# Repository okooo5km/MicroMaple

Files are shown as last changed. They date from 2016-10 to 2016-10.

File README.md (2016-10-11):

# Micro Maple

**Micro Maple** is an opensource hardware like **Maple mini** created by Leaflab and disigned to realize our idea and creat our works more quickly and simply ! 

Basically, **STM32F103C8T6** works as the core -- it's very cheap and enough for our most ideas!

The features of **STM32F103C8T6**:

- ARM 32bits Cortex-M3 CPU
  - 72MHz, 1.25DMips/MHz(Dhrystone 2.1)
  - single cycle for Multiplication and Division
- 64K FLASH And 20K SRAM
- Two 12bits ADC, 1 us for transition
- 7 channel DMA for USART\Timer\ADC\SPI\IIC
- 16 External Interrupt
- 7 Timer
- Interface
  - 2 IIC
  - 3 USART
  - 3 SPI
  - CAN
  - USB2.0

# Micro Maple (中文)

**Micro Maple** 是类似于 **Maple Mini(由Leaflab设计)** 的开源硬件，设计初衷是让我们实现自己的想法和作品更加简单和快捷。

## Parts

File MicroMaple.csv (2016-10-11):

Reference | Value | Footprint | Datasheet
U1 | STM32F103C8T6 | Housings_QFP:LQFP-48_7x7mm_Pitch0.5mm
P1 | USB_OTG | myFootprints:USB_Micro-B-MK5
R3 | 22 | Resistors_SMD:R_0603
R4 | 22 | Resistors_SMD:R_0603
C5 | 47pF | Capacitors_SMD:C_0603
C6 | 47pF | Capacitors_SMD:C_0603
U2 | XC6206P332MR | TO_SOT_Packages_SMD:SOT-23
U3 | XC6206P332MR | TO_SOT_Packages_SMD:SOT-23
C8 | 10uF | Capacitors_SMD:C_0603
C9 | 10uF | Capacitors_SMD:C_0603
C7 | 100uF | SMD_Packages:SMD-1210_Pol
R8 | 0 | Resistors_SMD:R_0603
P2 | CONN_01X14 | myFootprints:Connector_FAD_14x1
P3 | CONN_01X14 | myFootprints:Connector_FAD_14x1
C2 | 1uF | Capacitors_SMD:C_0603
C3 | 1uF | Capacitors_SMD:C_0603
C4 | 1uF | Capacitors_SMD:C_0603
C1 | 1uF | Capacitors_SMD:C_0603
X1 | 8MHz_OSC | myFootprints:Resonator_3.2x1.5mm
C10 | 18pF | Capacitors_SMD:C_0603
C11 | 18pF | Capacitors_SMD:C_0603
R12 | 1K | Resistors_SMD:R_0603
D3 | GREEN | LEDs:LED_0603
R9 | 1K | Resistors_SMD:R_0603
D2 | PWR | LEDs:LED_0603
SW1 | USR_BUT | Buttons_Switches_SMD:SW_SPST_EVQP7C
R11 | 10K | Resistors_SMD:R_0603
R10 | 1K | Resistors_SMD:R_0603
R14 | 1K | Resistors_SMD:R_0603
R13 | 10K | Resistors_SMD:R_0603
SW2 | RST_BUTTON | Buttons_Switches_SMD:SW_SPST_EVQP7C
P4 | CONN_01X12 | myFootprints:Connector_FAD_12x1
R7 | 1.5K | Resistors_SMD:R_0603
R6 | 36K | Resistors_SMD:R_0603
R1 | 1K | Resistors_SMD:R_0603
R5 | 10K | Resistors_SMD:R_0603
R2 | 47K | Resistors_SMD:R_0603
Q1 | 8050 | TO_SOT_Packages_SMD:SOT-23
Q2 | 8050 | TO_SOT_Packages_SMD:SOT-23
D1 | D_Small | Diodes_SMD:SOD-123
P5 | CONN_01X01 | myFootprints:Debug_Pin_1
P6 | CONN_01X01 | myFootprints:Debug_Pin_1
P7 | CONN_01X01 | myFootprints:Debug_Pin_1
P8 | CONN_01X01 | myFootprints:Debug_Pin_1

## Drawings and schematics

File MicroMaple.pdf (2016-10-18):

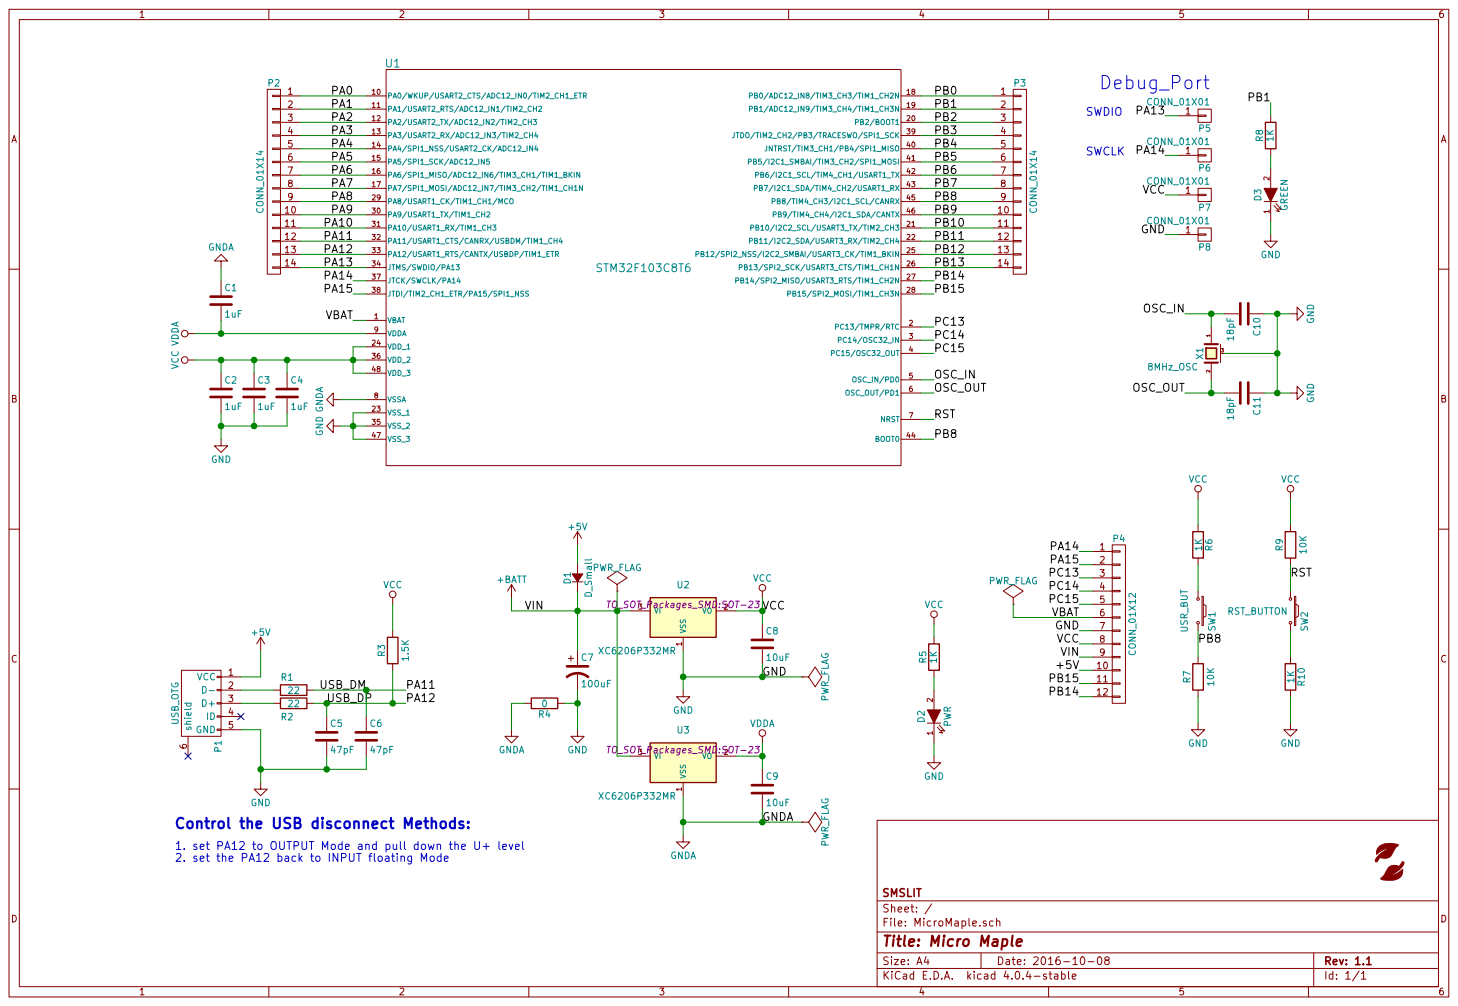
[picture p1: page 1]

14 P2 CONN_01X14 5 | 5

10 | 10
11 | 11
12 | 12
13 | 13

1 2 D2 PWR GND VCC USR_BUT SW1 R7 10K 1KR6 VCC

Control the USB disconnect Methods:

1. set PA12 to OUTPUT Mode and pull down the U+ level
2. set the PA12 back to INPUT floating Mode

File: MicroMaple.sch Sheet: / SMSLIT

Id: 1/1 Title: Micro Maple

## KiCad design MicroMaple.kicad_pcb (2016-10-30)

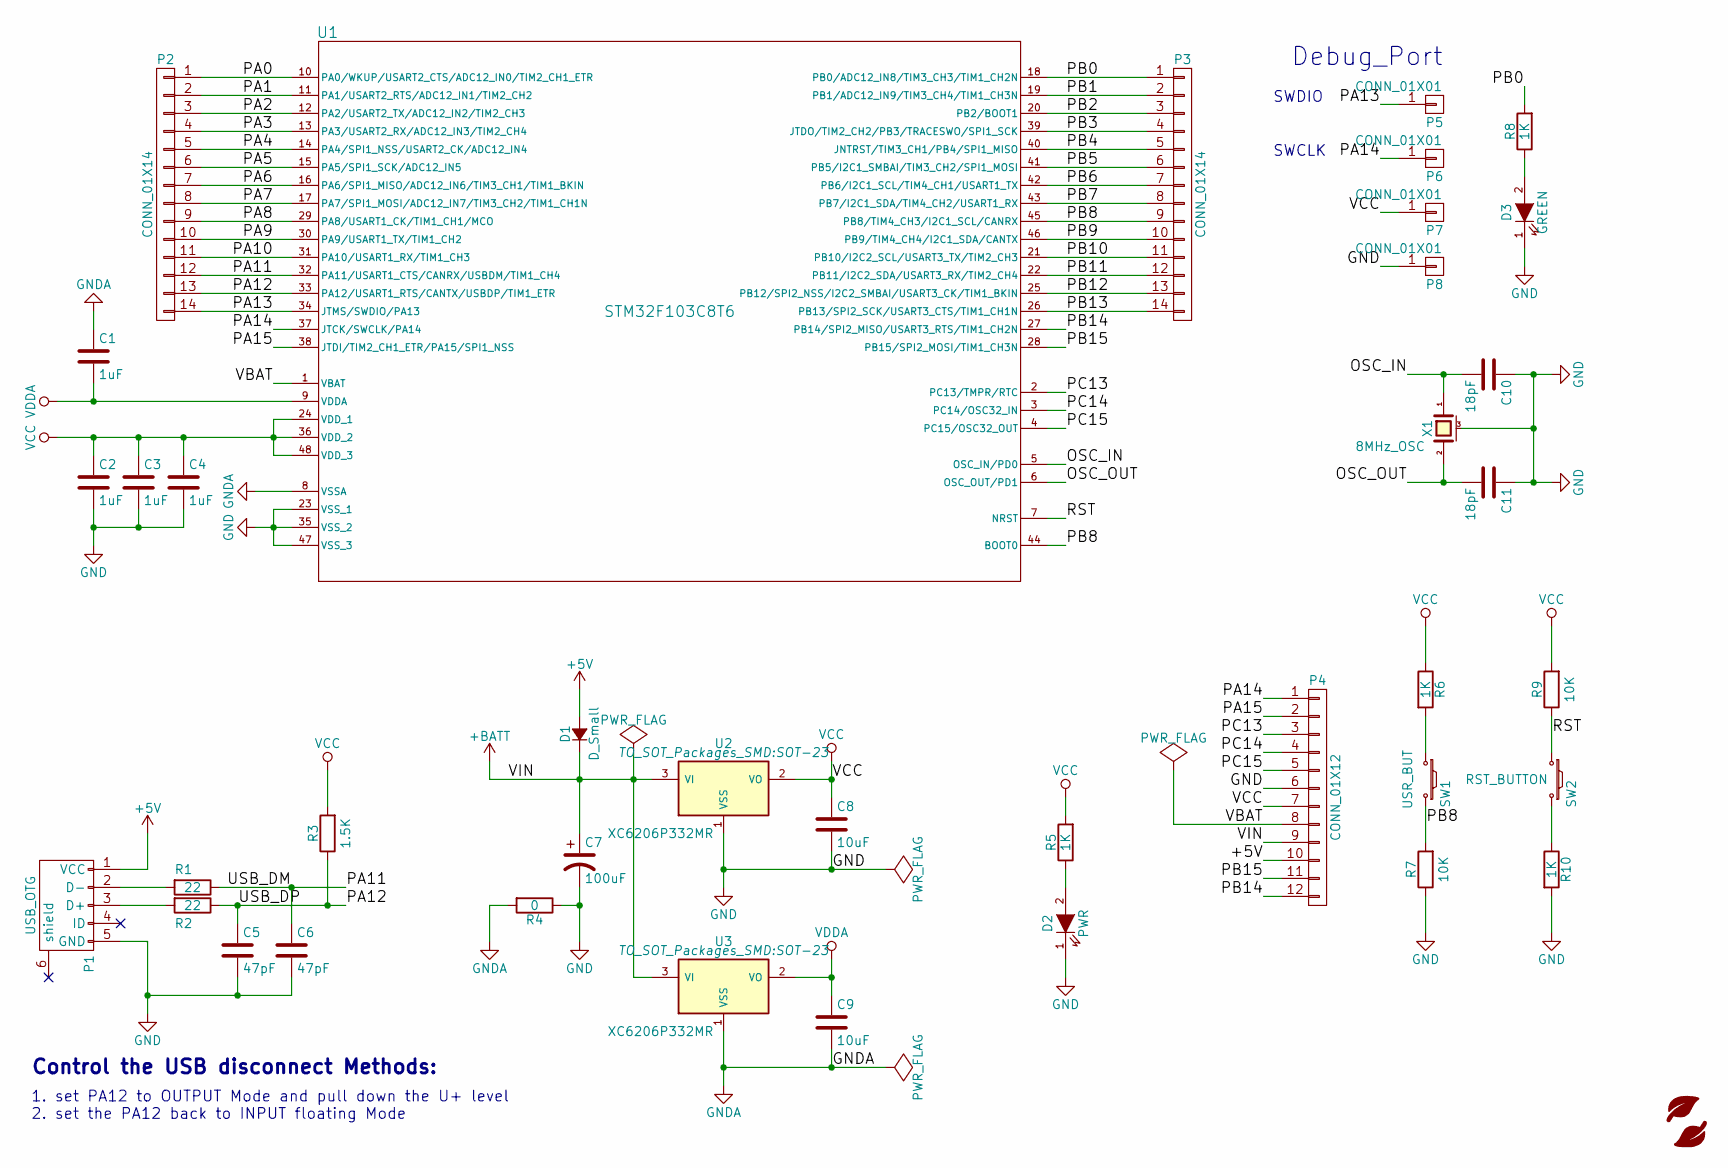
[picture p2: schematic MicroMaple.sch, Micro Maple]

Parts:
C1, C2, C3, C4: 1uF; C_0603
C5, C6: 47pF; C_0603
C7: 100uF; SMD-1210_Pol
C8, C9: 10uF; C_0603
C10, C11: 18pF; C_0603
D1: D_Small; SOD-123
D2: PWR; LED_0603
D3: GREEN; LED_0603
P1: USB_OTG; USB_Micro-B-MK5
P2, P3: CONN_01X14; Connector_FAD_14x1
P4: CONN_01X12; Connector_FAD_12x1
P5, P6, P7, P8: CONN_01X01; Debug_Pin_1
R1, R2: 22; R_0603
R3: 1.5K; R_0603
R4: 0; R_0603
R5, R6, R8, R10: 1K; R_0603
R7, R9: 10K; R_0603
SW1: USR_BUT; SW_SPST_EVQP7C
SW2: RST_BUTTON; SW_SPST_EVQP7C
U1: STM32F103C8T6; LQFP-48_7x7mm_Pitch0.5mm
U2, U3: XC6206P332MR; SOT-23
X1: 8MHz_OSC; Resonator_3.2x1.5mm

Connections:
+5V: D1.2 (A), P1.1 (VCC), P4.10
+BATT: C7.1, D1.1 (K), P4.9, U2.3 (VI), U3.3 (VI)
/OSC_IN: C10.2, U1.5 (OSC_IN/PD0), X1.1
/OSC_OUT: C11.2, U1.6 (OSC_OUT/PD1), X1.2
/PA0: P2.1, U1.10 (PA0/WKUP/USART2_CTS/ADC12_IN0/TIM2_CH1_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)
/PA1: P2.2, U1.11 (PA1/USART2_RTS/ADC12_IN1/TIM2_CH2)
/PA2: P2.3, U1.12 (PA2/USART2_TX/ADC12_IN2/TIM2_CH3)
/PA3: P2.4, U1.13 (PA3/USART2_RX/ADC12_IN3/TIM2_CH4)
/PA4: P2.5, U1.14 (PA4/SPI1_NSS/USART2_CK/ADC12_IN4)
/PA5: P2.6, U1.15 (PA5/SPI1_SCK/ADC12_IN5)
/PA6: P2.7, U1.16 (PA6/SPI1_MISO/ADC12_IN6/TIM3_CH1/TIM1_B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)
/PA7: P2.8, U1.17 (PA7/SPI1_MOSI/ADC12_IN7/TIM3_CH2/TIM1_C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)
/PA8: P2.9, U1.29 (PA8/USART1_CK/TIM1_CH1/MCO)
/PA9: P2.10, U1.30 (PA9/USART1_TX/TIM1_CH2)
/PA10: P2.11, U1.31 (PA10/USART1_RX/TIM1_CH3)
/PA11: C6.1, P2.12, R1.1, U1.32 (PA11/USART1_CTS/CANRX/USBDM/TIM1_CH4)
/PA12: C5.1, P2.13, R2.1, R3.1, U1.33 (PA12/USART1_RTS/CANTX/USBDP/TIM1_ETR)
/PA13: P2.14, P5.1, U1.34 (JTMS/SWDIO/PA13)
/PA14: P4.1, P6.1, U1.37 (JTCK/SWCLK/PA14)
/PA15: P4.2, U1.38 (JTDI/TIM2_CH1_ETR/PA15/SPI1_NSS)
/PB0: P3.1, R8.2, U1.18 (PB0/ADC12_IN8/TIM3_CH3/TIM1_CH2N)
/PB1: P3.2, U1.19 (PB1/ADC12_IN9/TIM3_CH4/TIM1_CH3N)
/PB2: P3.3, U1.20 (PB2/BOOT1)
/PB3: P3.4, U1.39 (JTDO/TIM2_CH2/PB3/TRACESWO/SPI1_SCK)
/PB4: P3.5, U1.40 (JNTRST/TIM3_CH1/PB4/SPI1_MISO)
/PB5: P3.6, U1.41 (PB5/I2C1_SMBAI/TIM3_CH2/SPI1_MOSI)
/PB6: P3.7, U1.42 (PB6/I2C1_SCL/TIM4_CH1/USART1_TX)
/PB7: P3.8, U1.43 (PB7/I2C1_SDA/TIM4_CH2/USART1_RX)
/PB8: P3.9, R7.2, SW1.2, U1.44 (BOOT0), U1.45 (PB8/TIM4_CH3/I2C1_SCL/CANRX)
/PB9: P3.10, U1.46 (PB9/TIM4_CH4/I2C1_SDA/CANTX)
/PB10: P3.11, U1.21 (PB10/I2C2_SCL/USART3_TX/TIM2_CH3)
/PB11: P3.12, U1.22 (PB11/I2C2_SDA/USART3_RX/TIM2_CH4)
/PB12: P3.13, U1.25 (PB12/SPI2_NSS/I2C2_SMBAI/USART3_CK/TIM1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)
/PB13: P3.14, U1.26 (PB13/SPI2_SCK/USART3_CTS/TIM1_CH1N)
/PB14: P4.12, U1.27 (PB14/SPI2_MISO/USART3_RTS/TIM1_CH2N)
/PB15: P4.11, U1.28 (PB15/SPI2_MOSI/TIM1_CH3N)
/PC13: P4.3, U1.2 (PC13/TMPR/RTC)
/PC14: P4.4, U1.3 (PC14/OSC32_IN)
/PC15: P4.5, U1.4 (PC15/OSC32_OUT)
/RST: R9.1, SW2.1, U1.7 (NRST)
/VBAT: P4.8, U1.1 (VBAT)
GND: C2.2, C3.2, C4.2, C5.2, C6.2, C7.2, C8.2, C10.1, C11.1, D2.1 (K), D3.1 (K), P1.5 (GND), P4.6, P8.1, R4.1, R7.1, R10.2, U1.23 (VSS_1), U1.35 (VSS_2), U1.47 (VSS_3), U2.1 (VSS), X1.3 (case)
GNDA: C1.1, C9.2, R4.2, U1.8 (VSSA), U3.1 (VSS)
unnamed: D2.2 (A), R5.1
unnamed: D3.2 (A), R8.1
unnamed: P1.2 (D-), R1.2
unnamed: P1.3 (D+), R2.2
unnamed: R6.2, SW1.1
unnamed: R10.1, SW2.2
VCC: C2.1, C3.1, C4.1, C8.1, P4.7, P7.1, R3.2, R5.2, R6.1, R9.2, U1.24 (VDD_1), U1.36 (VDD_2), U1.48 (VDD_3), U2.2 (VO)
VDDA: C1.2, C9.1, U1.9 (VDDA), U3.2 (VO)

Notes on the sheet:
Debug_Port
SWDIO
SWCLK
Control the USB disconnect Methods:
1. set PA12 to OUTPUT Mode and pull down the U+ level 2. set the PA12 back to INPUT floating Mode

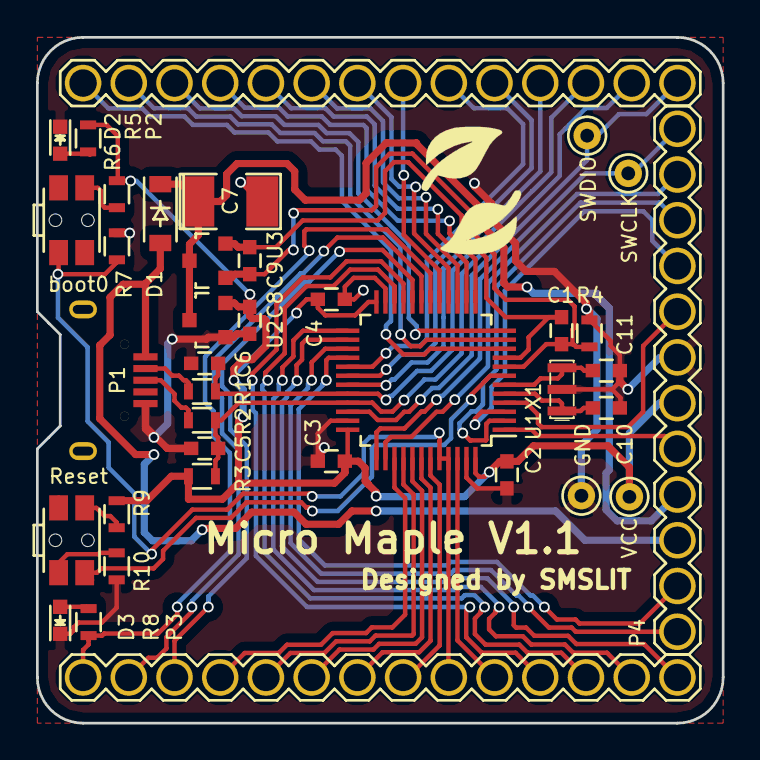
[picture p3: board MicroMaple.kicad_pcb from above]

Board: 2 copper layers, 38.1 x 38.1 mm, 38 parts (0 on the bottom side), 51 nets.

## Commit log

2016-10-08 add the some libs
    [MicroMaple.kicad_pcb, MicroMaple.sch]
2016-10-08 finish the sch, and assign some footprints, update the README.md
    [MicroMaple.sch]
2016-10-09 finish assign the footprints and begin the PCB design
    [MicroMaple.kicad_pcb, MicroMaple.sch]
2016-10-09 finish the PCB layout and track
    [MicroMaple.kicad_pcb]
2016-10-10 finish the PCB design
    [MicroMaple.kicad_pcb, MicroMaple.sch]
2016-10-10 optimize the layout and tracks, then add the logo and some text
    [MicroMaple.kicad_pcb]
2016-10-10 plot the gerber files and drill file
    [MicroMaple-B.Cu.gbr, MicroMaple-B.Mask.gbr, MicroMaple-B.SilkS.gbr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]
2016-10-11 export the BOM
    [MicroMaple.csv]
2016-10-12 update the sch file
    [MicroMaple.sch]
2016-10-18 1.remove the USB disconnect circuit. 2.export v1.1 pdf. 3.add smslit logo lib
    [MicroMaple.kicad_pcb, MicroMaple.sch]
2016-10-19 add the pinmap xlsx file and encorrect the Bsilks text for pins.
    [MicroMaple.kicad_pcb, pinmap.xlsx]
2016-10-23 Micro Maple Version1.1 : 1. update the sch and netlist file; 2. finish pcb trace layout
    [MicroMaple.kicad_pcb, MicroMaple.sch]
2016-10-24 V1.1: update the pcb desgin
    [MicroMaple.kicad_pcb]
2016-10-30 because the mistake in m2OLED pcb design, change the position of GND\VCC\VBAT
    [MicroMaple.kicad_pcb, MicroMaple.sch]
